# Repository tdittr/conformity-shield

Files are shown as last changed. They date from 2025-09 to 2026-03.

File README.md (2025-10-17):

# Conformity Shield

This is a design for a Arduino Uno R3 compatible shield, that connects an RP2354B to all IO pins. It is inteded to be used to test implementations of [`embedded-hal`](https://docs.rs/embedded-hal/).

**Warning:** rev1 of this board has known problems, do not produce boards from this yet, see the issue tracker for details!

## License

This project is licensed under the [CERN-OHL-P license](LICENSE), except for the contents of [`ProjectSpecific.pretty`](ProjectSpecific.pretty) and [`Project_Specific.kicad_sym`](Project_Specific.kicad_sym) which are partially copied from the [RP235xB example](https://datasheets.raspberrypi.com/rp2350/hardware-design-with-rp2350.pdf) by Raspberry Pi.

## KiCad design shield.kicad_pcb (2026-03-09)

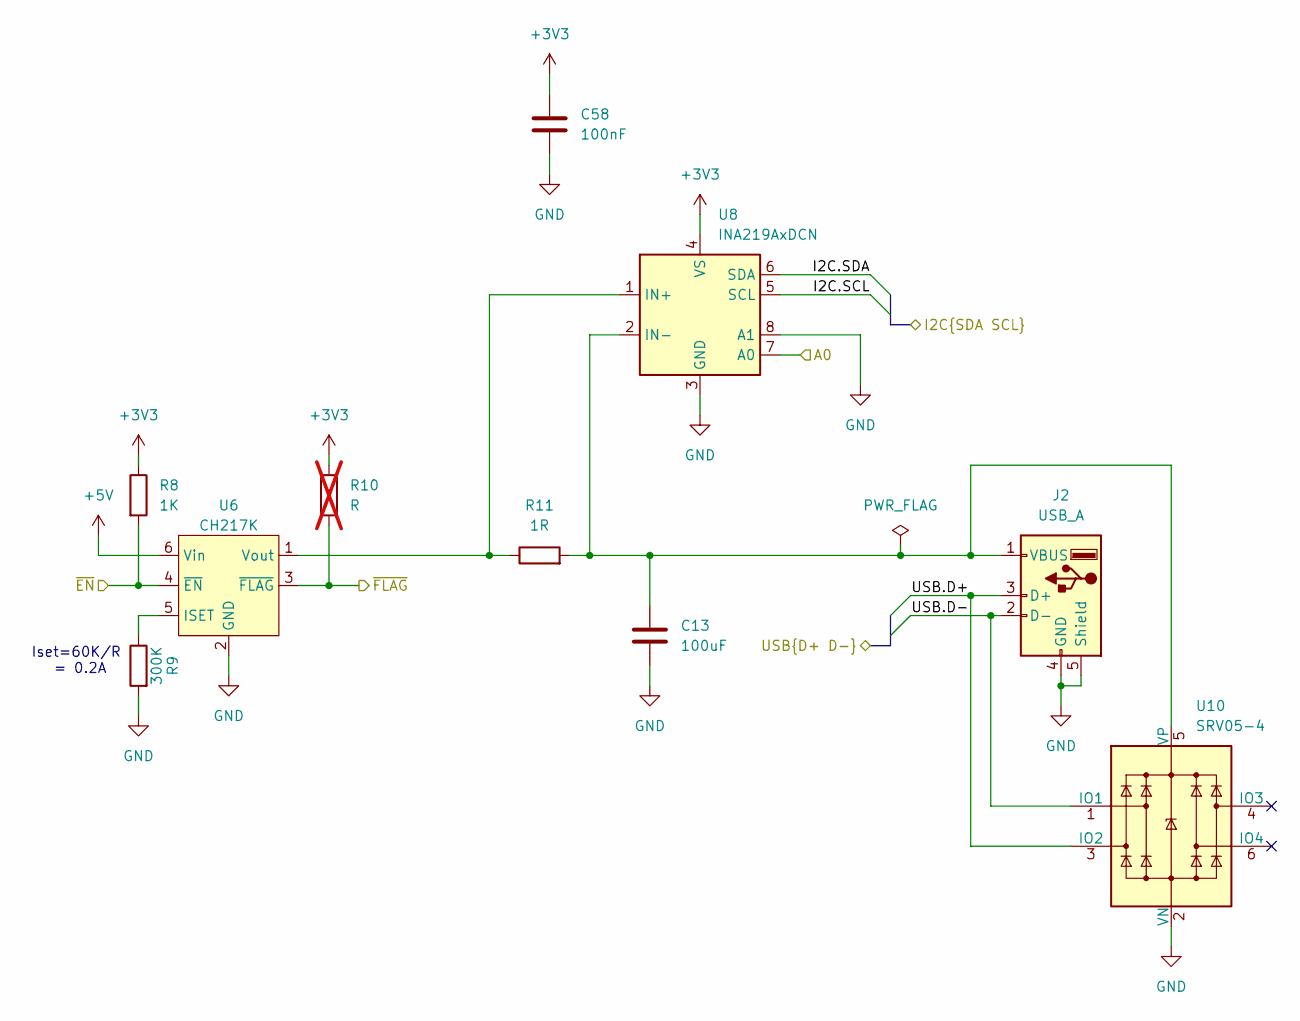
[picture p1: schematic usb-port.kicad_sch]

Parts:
C13: 100uF; C_1206_3216Metric; LCSC C15008
C58: 100nF; C_0402_1005Metric; LCSC C1525
J2: USB_A; USB_A_Receptacle_GCT_USB1046; LCSC C6307429
R8: 1K; R_0402_1005Metric; LCSC C11702
R9: 300K; R_0603_1608Metric; LCSC C23024
R10: R; R_0603_1608Metric_Pad0.98x0.95mm_HandSolder; not fitted
R11: 1R; R_0402_1005Metric; LCSC C25086
U6: CH217K; SOT-23-6; LCSC C7462749
U8: INA219AxDCN; SOT-23-8; LCSC C87469
U10: SRV05-4; SOT-23-6; LCSC C7420376

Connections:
+3V3: C58.1, R8.1, R10.1, U8.4 (VS), U8.7 (A0); also elsewhere on the board
+5V: U6.6 (Vin); also elsewhere on the board
/Tester/EN_USB_0: R8.2, U6.4 (~EN); also elsewhere on the board
/Tester/FLAG_USB_0: R10.2, U6.3 (~FLAG); also elsewhere on the board
/Tester/I2C.SCL: U8.5 (SCL); also elsewhere on the board
/Tester/I2C.SDA: U8.6 (SDA); also elsewhere on the board
/USB/USB1.D+: J2.3 (D+), U10.3 (IO2); also elsewhere on the board
/USB/USB1.D-: J2.2 (D-), U10.1 (IO1); also elsewhere on the board
GND: C13.2, C58.2, J2.4 (GND), J2.5 (Shield), R9.2, U6.2 (GND), U8.3 (GND), U8.8 (A1), U10.2 (VN); also elsewhere on the board
unnamed: C13.1, J2.1 (VBUS), R11.2, U8.2 (IN-), U10.5 (VP)
unnamed: R9.1, U6.5 (ISET)
unnamed: R11.1, U6.1 (Vout), U8.1 (IN+)

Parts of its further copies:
C52: 100uF; C_1206_3216Metric; LCSC C15008
C59: 100nF; C_0402_1005Metric; LCSC C1525
J3: USB_A; USB_A_Receptacle_GCT_USB1046; LCSC C6307429
R12: 1K; R_0402_1005Metric; LCSC C11702
R13: 300K; R_0603_1608Metric; LCSC C23024
R14: R; R_0603_1608Metric_Pad0.98x0.95mm_HandSolder; not fitted
R15: 1R; R_0402_1005Metric; LCSC C25086
U7: CH217K; SOT-23-6; LCSC C7462749
U9: INA219AxDCN; SOT-23-8; LCSC C87469
U11: SRV05-4; SOT-23-6; LCSC C7420376

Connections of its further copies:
+3V3: C59.1, R12.1, R14.1, U9.4 (VS); also elsewhere on the board
+5V: U7.6 (Vin); also elsewhere on the board
/Tester/EN_USB_1: R12.2, U7.4 (~EN); also elsewhere on the board
/Tester/FLAG_USB_1: R14.2, U7.3 (~FLAG); also elsewhere on the board
/Tester/I2C.SCL: U9.5 (SCL); also elsewhere on the board
/Tester/I2C.SDA: U9.6 (SDA); also elsewhere on the board
/USB Mux/USB.D+: J3.3 (D+), U11.3 (IO2); also elsewhere on the board
/USB Mux/USB.D-: J3.2 (D-), U11.1 (IO1); also elsewhere on the board
GND: C52.2, C59.2, J3.4 (GND), J3.5 (Shield), R13.2, U7.2 (GND), U9.3 (GND), U9.7 (A0), U9.8 (A1), U11.2 (VN); also elsewhere on the board
unnamed: C52.1, J3.1 (VBUS), R15.2, U9.2 (IN-), U11.5 (VP)
unnamed: R13.1, U7.5 (ISET)
unnamed: R15.1, U7.1 (Vout), U9.1 (IN+)

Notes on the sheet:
Iset=60K/R = 0.2A

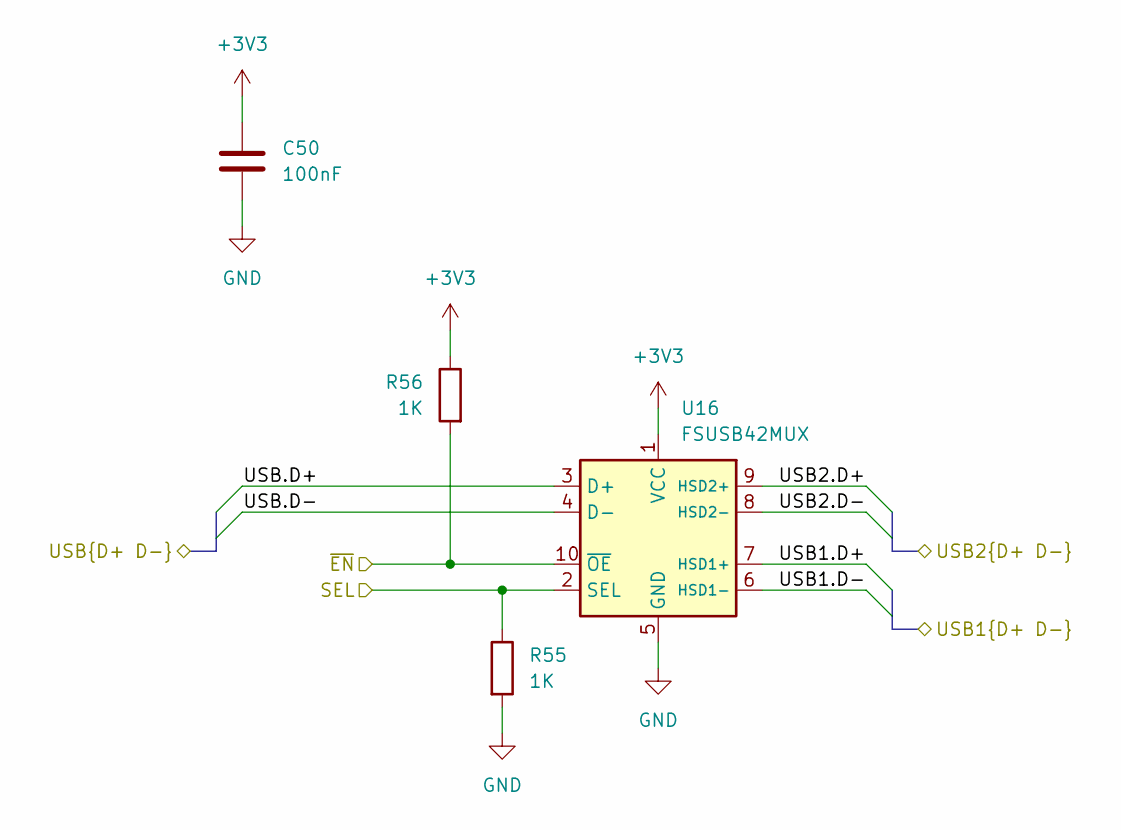
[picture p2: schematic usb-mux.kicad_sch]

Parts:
C50: 100nF; C_0402_1005Metric; LCSC C1525
R55, R56: 1K; R_0402_1005Metric; LCSC C11702
U16: FSUSB42MUX; MSOP-10_3x3mm_P0.5mm; LCSC C11355

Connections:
+3V3: C50.1, R56.1, U16.1 (VCC); also elsewhere on the board
/Tester/USBH.D+: U16.9 (HSD2+); also elsewhere on the board
/Tester/USBH.D-: U16.8 (HSD2-); also elsewhere on the board
/Tester/USBH_SEL: R55.1, U16.2 (SEL); also elsewhere on the board
/Tester/~USBH_EN: R56.2, U16.10 (~OE); also elsewhere on the board
/USB Mux/USB1.D+: U16.7 (HSD1+); also elsewhere on the board
/USB Mux/USB1.D-: U16.6 (HSD1-); also elsewhere on the board
/USB Mux/USB.D+: U16.3 (D+); also elsewhere on the board
/USB Mux/USB.D-: U16.4 (D-); also elsewhere on the board
GND: C50.2, R55.2, U16.5 (GND); also elsewhere on the board

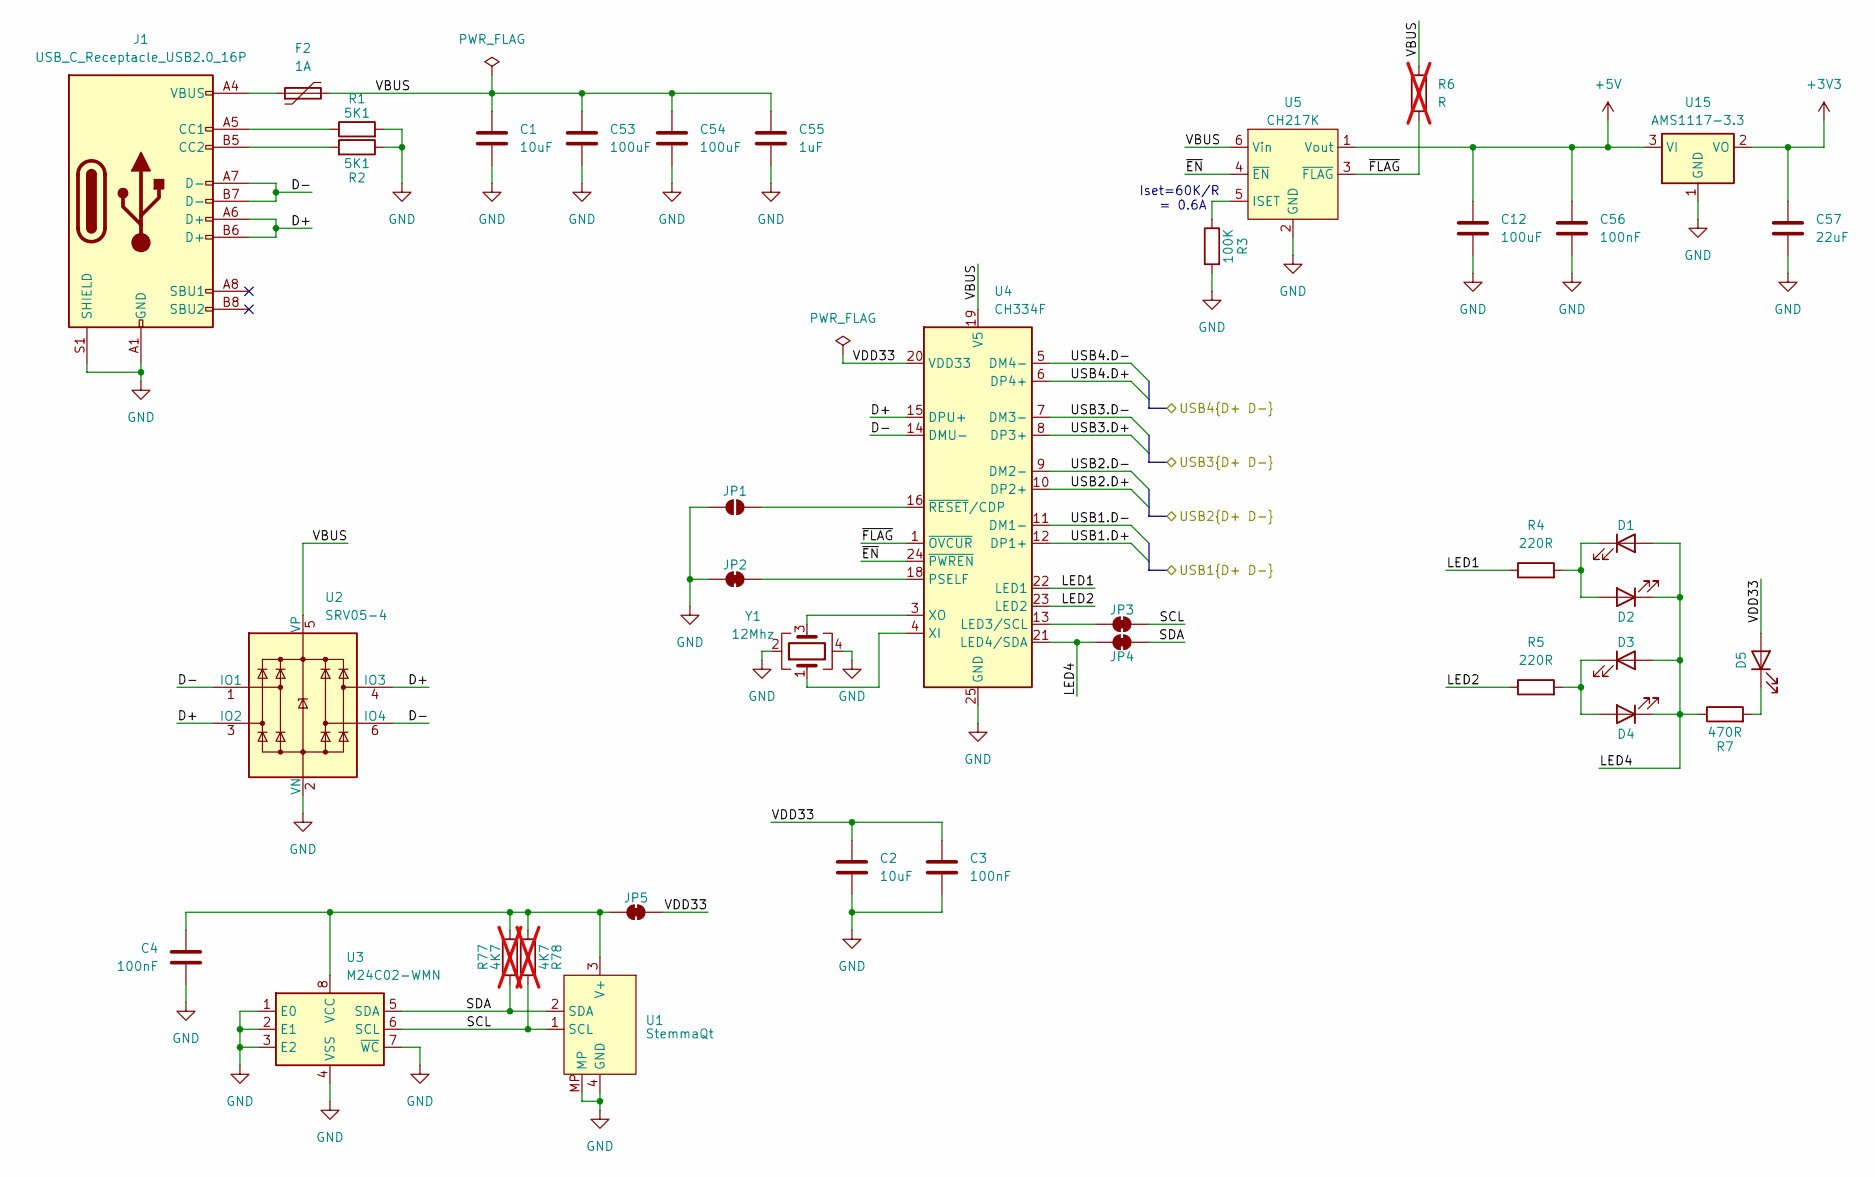
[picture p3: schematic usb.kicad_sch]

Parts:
C1, C2: 10uF; C_0402_1005Metric; LCSC C15525
C3, C4, C56: 100nF; C_0402_1005Metric; LCSC C1525
C12, C53, C54: 100uF; C_1206_3216Metric; LCSC C15008
C55: 1uF; C_0402_1005Metric; LCSC C52923
C57: 22uF; C_0805_2012Metric; LCSC C45783
D1, D2, D3, D4, D5: LED; LED_0805_2012Metric; LCSC C2297
F2: 1A; Fuse_1206_3216Metric_Pad1.42x1.75mm_HandSolder; LCSC C720075
J1: USB_C_Receptacle_USB2.0_16P; USB_C_Receptacle_G-Switch_GT-USB-7010ASV; LCSC C2988369
JP1: SolderJumper_2_Open; SolderJumper-2_P1.3mm_Open_RoundedPad1.0x1.5mm
JP2, JP3, JP4, JP5: SolderJumper_2_Bridged; SolderJumper-2_P1.3mm_Bridged_RoundedPad1.0x1.5mm
R1, R2: 5K1; R_0402_1005Metric; LCSC C25905
R3: 100K; R_0603_1608Metric; LCSC C23162
R4, R5: 220R; R_0402_1005Metric; LCSC C25091
R6: R; R_0603_1608Metric_Pad0.98x0.95mm_HandSolder; not fitted
R7: 470R; R_0402_1005Metric; LCSC C25117
R77, R78: 4K7; R_0402_1005Metric_Pad0.72x0.64mm_HandSolder; LCSC C25900; not fitted
U1: StemmaQt; JST_SH_SM04B-SRSS-TB_1x04-1MP_P1.00mm_Horizontal; LCSC C160404
U2: SRV05-4; SOT-23-6; LCSC C7420376
U3: M24C02-WMN; SOIC-8_3.9x4.9mm_P1.27mm; LCSC C7562
U4: CH334F; QFN-24-1EP_4x4mm_P0.5mm_EP2.7x2.7mm_ThermalVias; LCSC C5187527
U5: CH217K; SOT-23-6; LCSC C7462749
U15: AMS1117-3.3; SOT-223-3_TabPin2; LCSC C6186
Y1: 12Mhz; Crystal_SMD_3225-4Pin_3.2x2.5mm; LCSC C9002

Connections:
+3V3: C57.1, U15.2 (VO); also elsewhere on the board
+5V: C12.1, C56.1, U5.1 (Vout), U15.3 (VI); also elsewhere on the board
/Tester/USB.D+: U4.8 (DP3+); also elsewhere on the board
/Tester/USB.D-: U4.7 (DM3-); also elsewhere on the board
/USB Mux/USB1.D+: U4.10 (DP2+); also elsewhere on the board
/USB Mux/USB1.D-: U4.9 (DM2-); also elsewhere on the board
/USB/D+: J1.A6 (D+), J1.B6 (D+), U2.3 (IO2), U2.4 (IO3), U4.15 (DPU+)
/USB/D-: J1.A7 (D-), J1.B7 (D-), U2.1 (IO1), U2.6 (IO4), U4.14 (DMU-)
/USB/LED1: R4.1, U4.22 (LED1)
/USB/LED2: R5.1, U4.23 (LED2)
/USB/LED4: D1.2 (A), D2.1 (K), D3.2 (A), D4.1 (K), JP4.1 (A), R7.1, U4.21 (LED4/SDA)
/USB/SCL: JP3.2 (B), R78.1, U1.1 (SCL), U3.6 (SCL)
/USB/SDA: JP4.2 (B), R77.1, U1.2 (SDA), U3.5 (SDA)
/USB/USB1.D+: U4.12 (DP1+); also elsewhere on the board
/USB/USB1.D-: U4.11 (DM1-); also elsewhere on the board
/USB/USB4.D+: U4.6 (DP4+); also elsewhere on the board
/USB/USB4.D-: U4.5 (DM4-); also elsewhere on the board
/USB/VBUS: C1.1, C53.1, C54.1, C55.1, F2.2, R6.1, U2.5 (VP), U4.19 (V5), U5.6 (Vin)
/USB/VDD33: C2.1, C3.1, D5.2 (A), JP5.2 (B), U4.20 (VDD33)
/USB/~EN: U4.24 (~PWREN), U5.4 (~EN)
/USB/~FLAG: R6.2, U4.1 (~OVCUR), U5.3 (~FLAG)
GND: C1.2, C2.2, C3.2, C4.2, C12.2, C53.2, C54.2, C55.2, C56.2, C57.2, J1.A1 (GND), J1.A12 (GND), J1.B1 (GND), J1.B12 (GND), J1.S1 (SHIELD), JP1.1 (A), JP2.1 (A), R1.2, R2.1, R3.2, U1.4 (GND), U1.MP, U2.2 (VN), U3.1 (E0), U3.2 (E1), U3.3 (E2), U3.4 (VSS), U3.7 (~WC), U4.25 (GND), U5.2 (GND), U15.1 (GND), Y1.2, Y1.4; also elsewhere on the board
unnamed: D1.1 (K), D2.2 (A), R4.2
unnamed: D3.1 (K), D4.2 (A), R5.2
unnamed: D5.1 (K), R7.2
unnamed: F2.1, J1.A4 (VBUS), J1.A9 (VBUS), J1.B4 (VBUS), J1.B9 (VBUS)
unnamed: J1.A5 (CC1), R1.1
unnamed: J1.B5 (CC2), R2.2
unnamed: JP1.2 (B), U4.16 (~RESET/CDP)
unnamed: JP2.2 (B), U4.18 (PSELF)
unnamed: JP3.1 (A), U4.13 (LED3/SCL)
unnamed: C4.1, JP5.1 (A), R77.2, R78.2, U1.3 (V+), U3.8 (VCC)
unnamed: U4.4 (XI), Y1.1
unnamed: U4.3 (XO), Y1.3
unnamed: R3.1, U5.5 (ISET)

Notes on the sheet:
Iset=60K/R = 0.6A

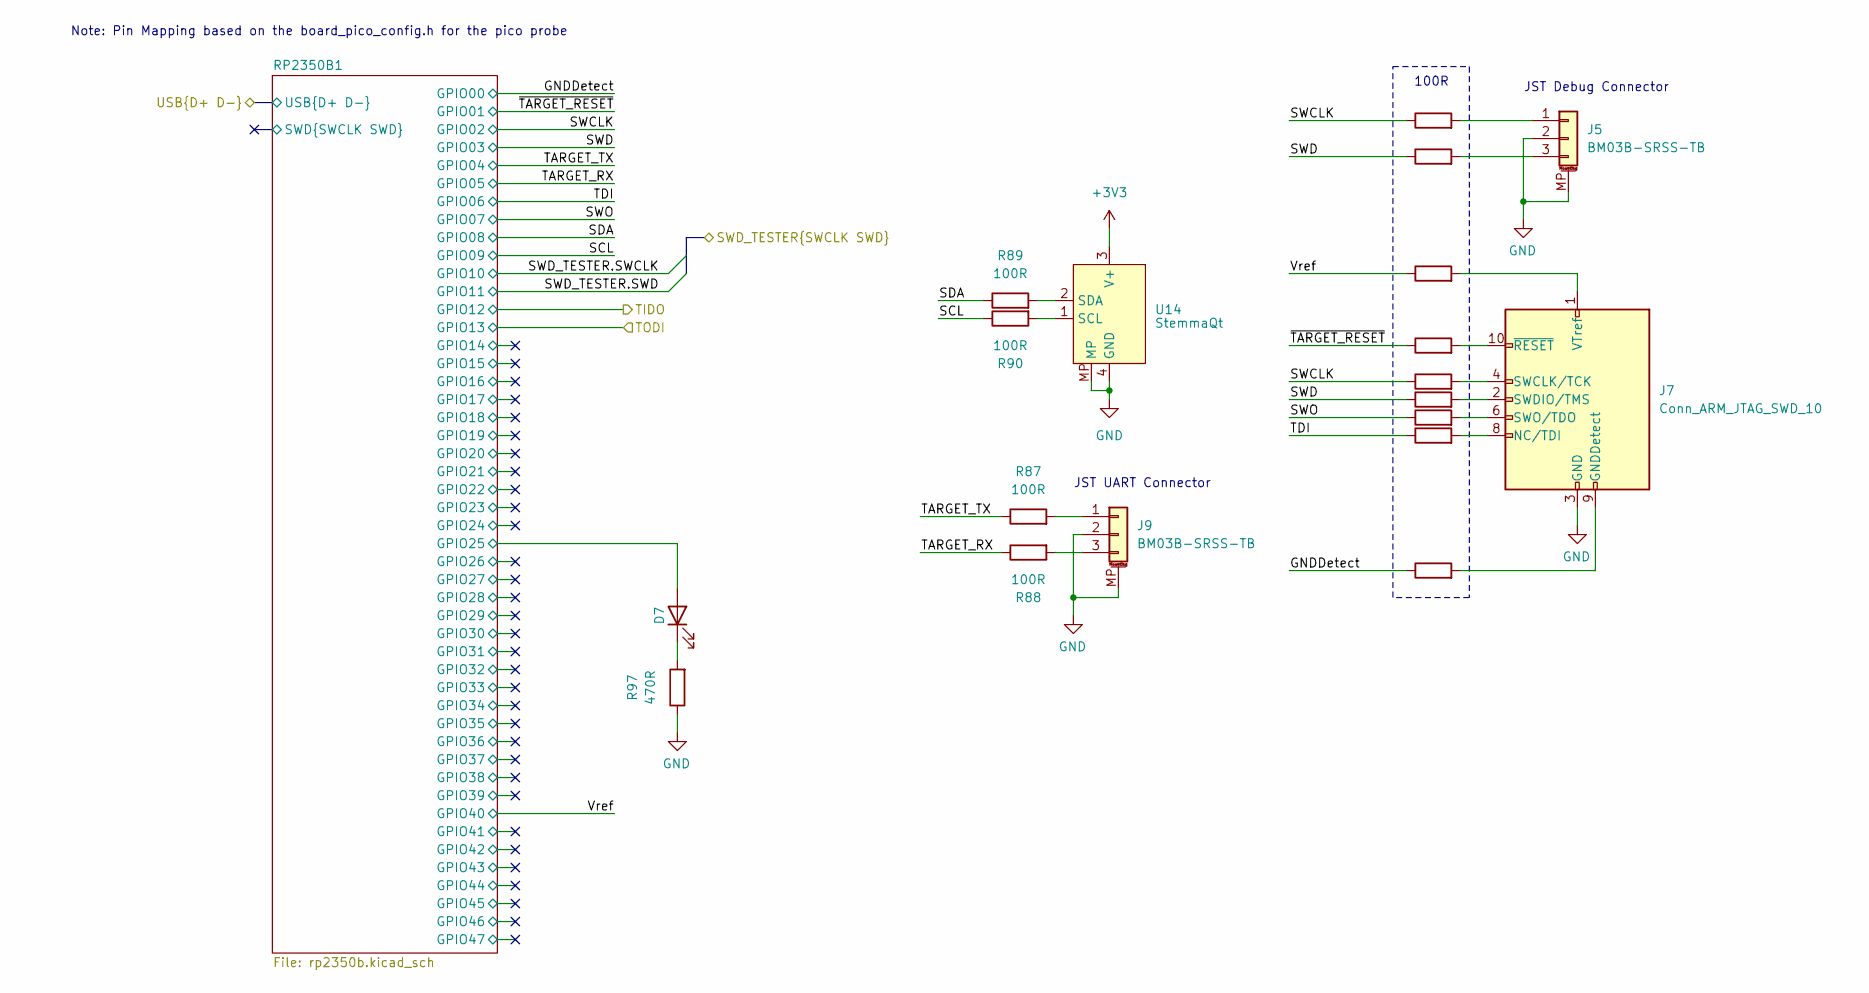
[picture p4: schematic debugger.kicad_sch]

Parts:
D7: LED; LED_0805_2012Metric; LCSC C2297
J5, J9: BM03B-SRSS-TB; JST_SH_BM03B-SRSS-TB_1x03-1MP_P1.00mm_Vertical; LCSC C160389
J7: Conn_ARM_JTAG_SWD_10; PinHeader_2x05_P1.27mm_Vertical_SMD_IDC; LCSC C42372555
R69, R70, R71, R72, R73, R74, R81, R85, R86, R87, R88, R89, R90: 100R; R_0402_1005Metric_Pad0.72x0.64mm_HandSolder; LCSC C25076
R97: 470R; R_0402_1005Metric_Pad0.72x0.64mm_HandSolder; LCSC C25117
U14: StemmaQt; JST_SH_SM04B-SRSS-TB_1x04-1MP_P1.00mm_Horizontal; LCSC C160404

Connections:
+3V3: U14.3 (V+); also elsewhere on the board
/debugger/GNDDetect: R81.1; also elsewhere on the board
/debugger/RP2350B1/GPIO25: D7.2 (A); also elsewhere on the board
/debugger/SCL: R90.1; also elsewhere on the board
/debugger/SDA: R89.1; also elsewhere on the board
/debugger/SWCLK: R71.1, R85.1; also elsewhere on the board
/debugger/SWD: R72.1, R86.1; also elsewhere on the board
/debugger/SWO: R73.1; also elsewhere on the board
/debugger/TARGET_RX: R88.1; also elsewhere on the board
/debugger/TARGET_TX: R87.1; also elsewhere on the board
/debugger/TDI: R74.1; also elsewhere on the board
/debugger/Vref: R69.1; also elsewhere on the board
/debugger/~TARGET_RESET: R70.1; also elsewhere on the board
GND: J5.2, J5.MP (MountPin), J7.3 (GND), J7.5 (GND), J9.2, J9.MP (MountPin), R97.1, U14.4 (GND), U14.MP; also elsewhere on the board
unnamed: D7.1 (K), R97.2
unnamed: J5.1, R85.2
unnamed: J5.3, R86.2
unnamed: J7.9 (GNDDetect), R81.2
unnamed: J7.8 (NC/TDI), R74.2
unnamed: J7.4 (SWCLK/TCK), R71.2
unnamed: J7.2 (SWDIO/TMS), R72.2
unnamed: J7.6 (SWO/TDO), R73.2
unnamed: J7.1 (VTref), R69.2
unnamed: J7.10 (~RESET), R70.2
unnamed: J9.1, R87.2
unnamed: J9.3, R88.2
unnamed: R90.2, U14.1 (SCL)
unnamed: R89.2, U14.2 (SDA)

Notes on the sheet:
Note: Pin Mapping based on the board_pico_config.h for the pico probe
JST UART Connector
100R
JST Debug Connector

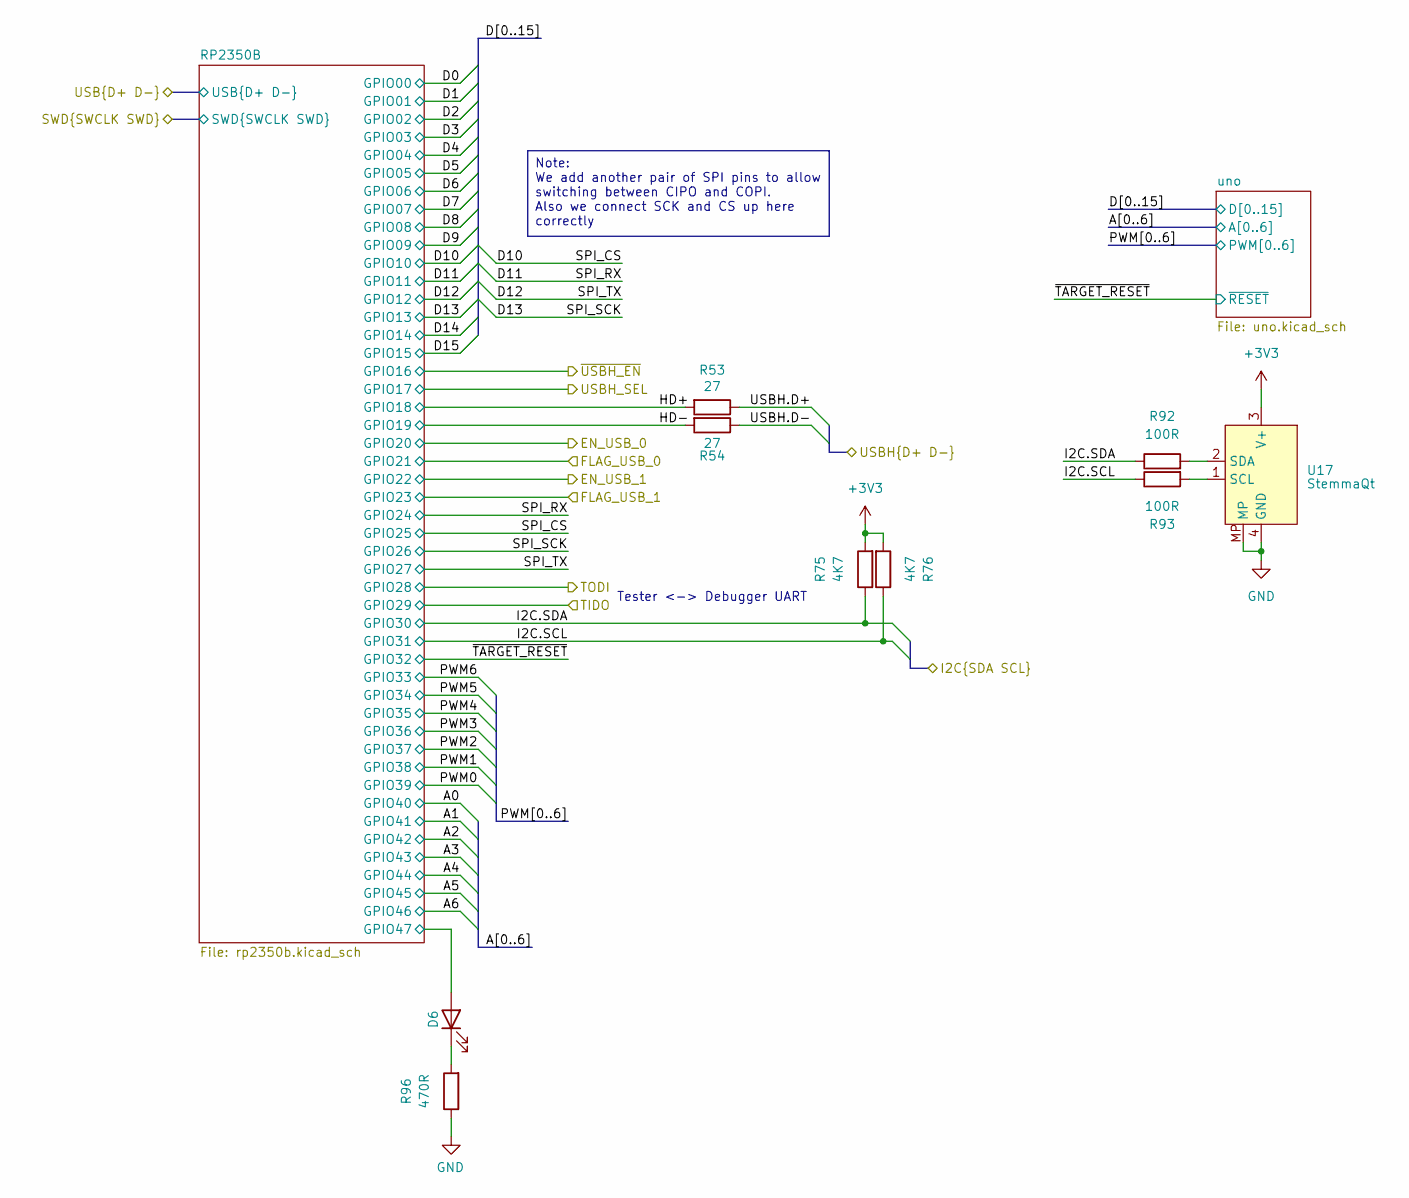
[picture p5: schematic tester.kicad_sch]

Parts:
D6: LED; LED_0805_2012Metric; LCSC C2297
R53, R54: 27; R_0402_1005Metric; LCSC C138021
R75, R76: 4K7; R_0402_1005Metric_Pad0.72x0.64mm_HandSolder; LCSC C25900
R92, R93: 100R; R_0402_1005Metric_Pad0.72x0.64mm_HandSolder; LCSC C25076
R96: 470R; R_0402_1005Metric_Pad0.72x0.64mm_HandSolder; LCSC C25117
U17: StemmaQt; JST_SH_SM04B-SRSS-TB_1x04-1MP_P1.00mm_Horizontal; LCSC C160404

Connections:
+3V3: R75.2, R76.2, U17.3 (V+); also elsewhere on the board
/Tester/HD+: R53.2; also elsewhere on the board
/Tester/HD-: R54.2; also elsewhere on the board
/Tester/I2C.SCL: R76.1, R93.1; also elsewhere on the board
/Tester/I2C.SDA: R75.1, R92.1; also elsewhere on the board
/Tester/RP2350B/GPIO47: D6.2 (A); also elsewhere on the board
/Tester/USBH.D+: R53.1; also elsewhere on the board
/Tester/USBH.D-: R54.1; also elsewhere on the board
GND: R96.1, U17.4 (GND), U17.MP; also elsewhere on the board
unnamed: D6.1 (K), R96.2
unnamed: R93.2, U17.1 (SCL)
unnamed: R92.2, U17.2 (SDA)

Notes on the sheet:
Tester <-> Debugger UART
Note: We add another pair of SPI pins to allow switching between CIPO and COPI. Also we connect SCK and CS up here correctly

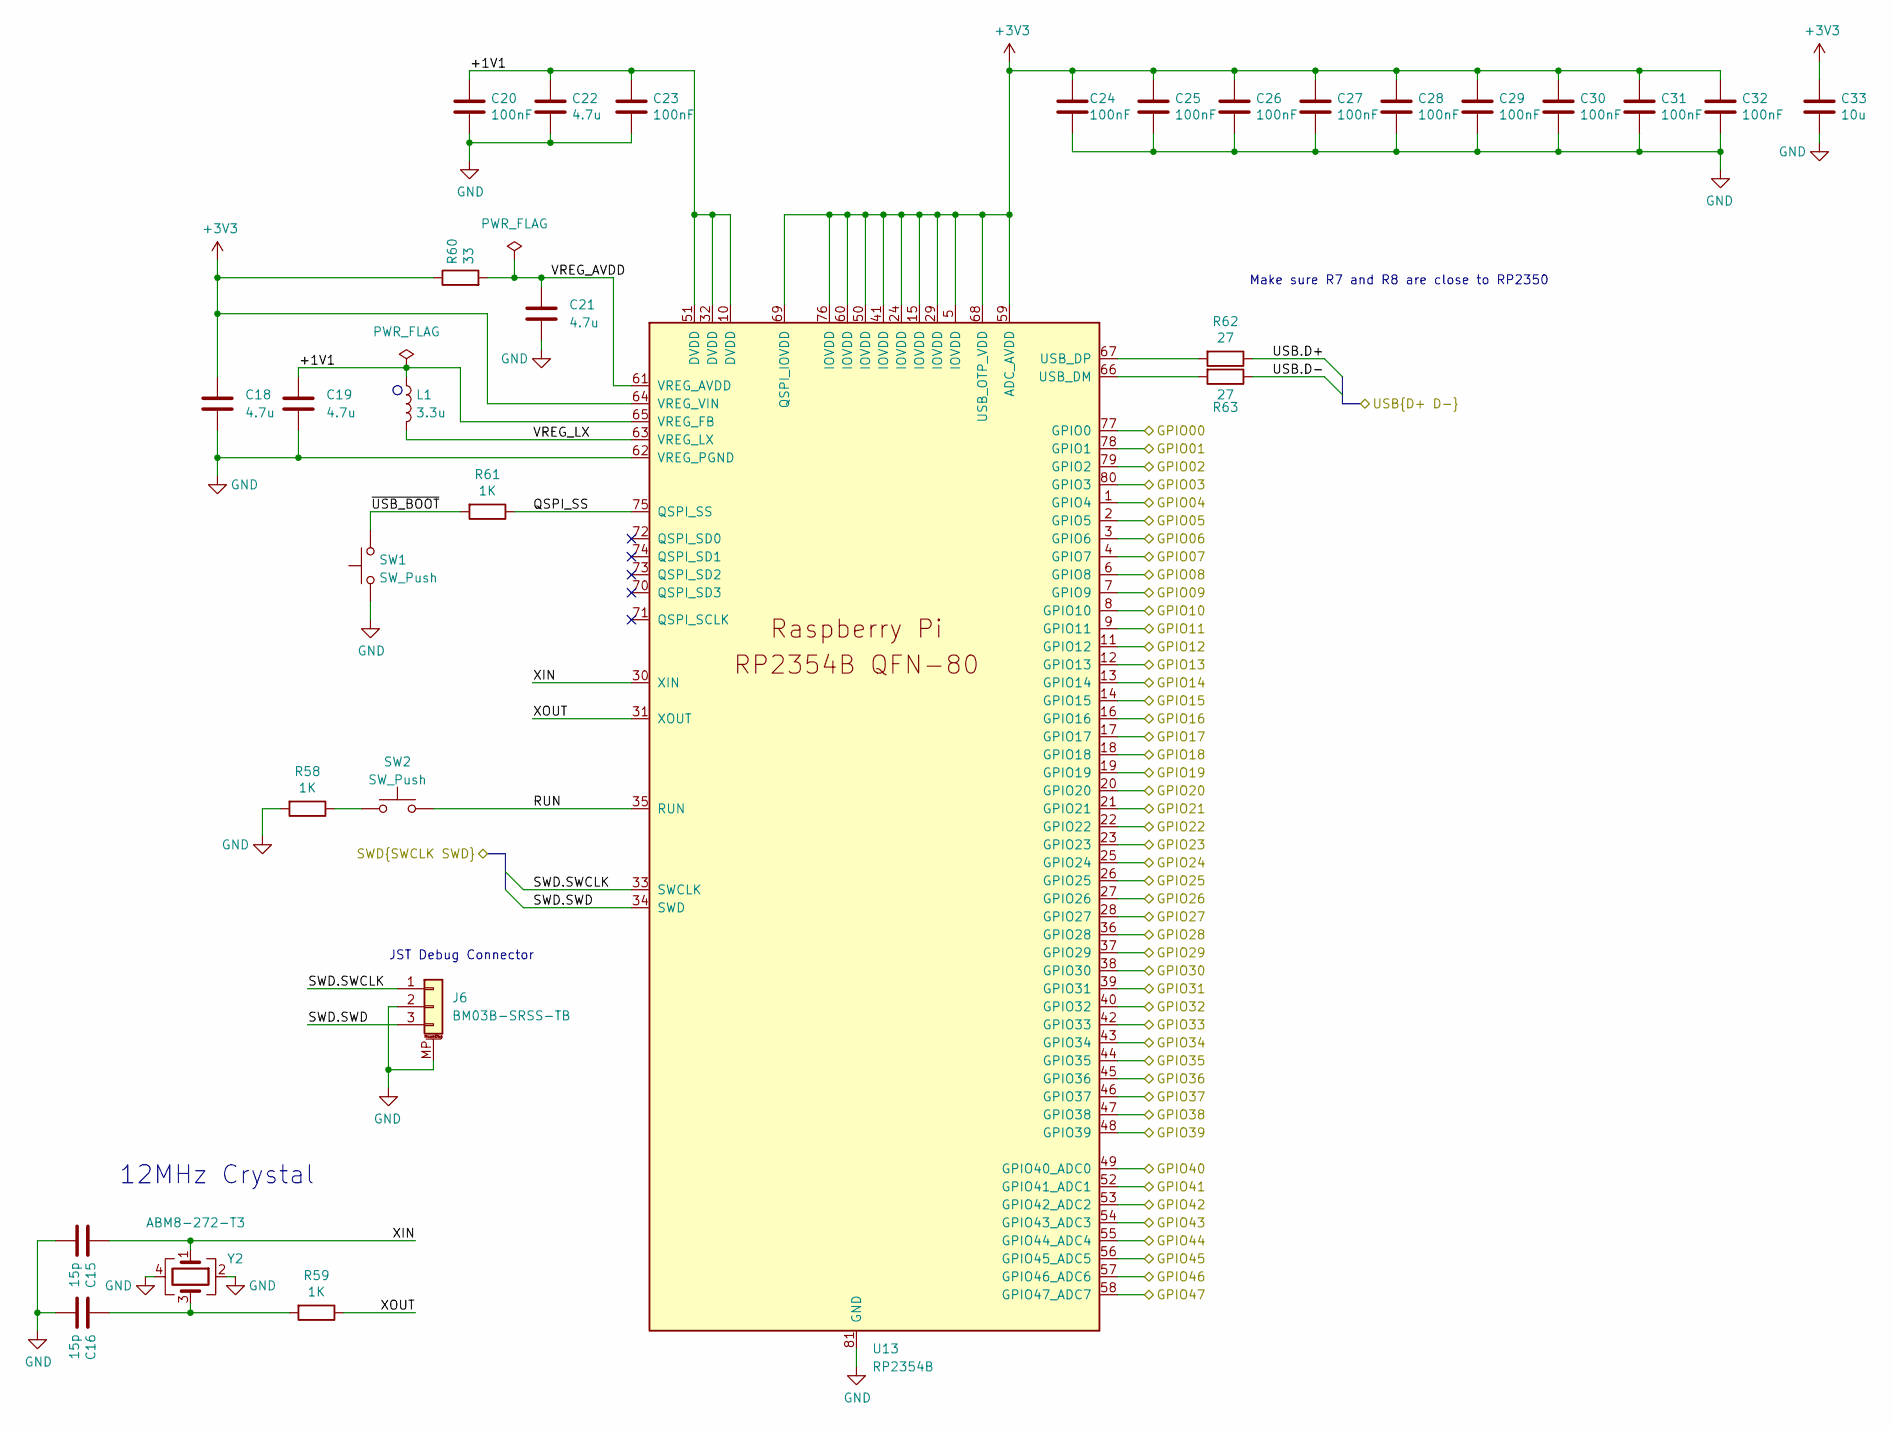
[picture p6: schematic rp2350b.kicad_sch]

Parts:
C15, C16: 15p; C_0402_1005Metric; LCSC C1548
C18, C19: 4.7u; C_0402_1005Metric_small_pads; LCSC C23733
C20, C23, C24, C25, C26, C27, C28, C29, C30, C31, C32: 100nF; C_0402_1005Metric; LCSC C1525
C21, C22: 4.7u; C_0402_1005Metric; LCSC C23733
C33: 10u; C_0805_2012Metric; LCSC C15850
J6: BM03B-SRSS-TB; JST_SH_BM03B-SRSS-TB_1x03-1MP_P1.00mm_Vertical; LCSC C160389
L1: 3.3u; L_pol_2016; LCSC C42411119
R58, R59, R61: 1K; R_0402_1005Metric; LCSC C11702
R60: 33; R_0402_1005Metric; LCSC C25105
R62, R63: 27; R_0402_1005Metric; LCSC C138021
SW1, SW2: SW_Push; SW_Push_1P1T_XKB_TS-1187A; LCSC C318884
U13: RP2354B; QFN-80-1EP_10x10mm_P0.4mm_EP3.4x3.4mm_ThermalVias; LCSC C39843328
Y2: ABM8-272-T3; Crystal_SMD_3225-4Pin_3.2x2.5mm; LCSC C20625731

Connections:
+3V3: C18.1, C24.1, C25.1, C26.1, C27.1, C28.1, C29.1, C30.1, C31.1, C32.1, C33.1, R60.1, U13.5 (IOVDD), U13.15 (IOVDD), U13.24 (IOVDD), U13.29 (IOVDD), U13.41 (IOVDD), U13.50 (IOVDD), U13.59 (ADC_AVDD), U13.60 (IOVDD), U13.64 (VREG_VIN), U13.68 (USB_OTP_VDD), U13.69 (QSPI_IOVDD), U13.76 (IOVDD); also elsewhere on the board
/Tester/A0: U13.49 (GPIO40_ADC0); also elsewhere on the board
/Tester/A1: U13.52 (GPIO41_ADC1); also elsewhere on the board
/Tester/A2: U13.53 (GPIO42_ADC2); also elsewhere on the board
/Tester/A3: U13.54 (GPIO43_ADC3); also elsewhere on the board
/Tester/A4: U13.55 (GPIO44_ADC4); also elsewhere on the board
/Tester/A5: U13.56 (GPIO45_ADC5); also elsewhere on the board
/Tester/A6: U13.57 (GPIO46_ADC6); also elsewhere on the board
/Tester/D0: U13.77 (GPIO0); also elsewhere on the board
/Tester/D1: U13.78 (GPIO1); also elsewhere on the board
/Tester/D2: U13.79 (GPIO2); also elsewhere on the board
/Tester/D3: U13.80 (GPIO3); also elsewhere on the board
/Tester/D4: U13.1 (GPIO4); also elsewhere on the board
/Tester/D5: U13.2 (GPIO5); also elsewhere on the board
/Tester/D6: U13.3 (GPIO6); also elsewhere on the board
/Tester/D7: U13.4 (GPIO7); also elsewhere on the board
/Tester/D8: U13.6 (GPIO8); also elsewhere on the board
/Tester/D9: U13.7 (GPIO9); also elsewhere on the board
/Tester/D10: U13.8 (GPIO10), U13.26 (GPIO25); also elsewhere on the board
/Tester/D11: U13.9 (GPIO11), U13.25 (GPIO24); also elsewhere on the board
/Tester/D12: U13.11 (GPIO12), U13.28 (GPIO27); also elsewhere on the board
/Tester/D13: U13.12 (GPIO13), U13.27 (GPIO26); also elsewhere on the board
/Tester/D14: U13.13 (GPIO14); also elsewhere on the board
/Tester/D15: U13.14 (GPIO15); also elsewhere on the board
/Tester/EN_USB_0: U13.20 (GPIO20); also elsewhere on the board
/Tester/EN_USB_1: U13.22 (GPIO22); also elsewhere on the board
/Tester/FLAG_USB_0: U13.21 (GPIO21); also elsewhere on the board
/Tester/FLAG_USB_1: U13.23 (GPIO23); also elsewhere on the board
/Tester/HD+: U13.18 (GPIO18); also elsewhere on the board
/Tester/HD-: U13.19 (GPIO19); also elsewhere on the board
/Tester/I2C.SCL: U13.39 (GPIO31); also elsewhere on the board
/Tester/I2C.SDA: U13.38 (GPIO30); also elsewhere on the board
/Tester/PWM0: U13.48 (GPIO39); also elsewhere on the board
/Tester/PWM1: U13.47 (GPIO38); also elsewhere on the board
/Tester/PWM2: U13.46 (GPIO37); also elsewhere on the board
/Tester/PWM3: U13.45 (GPIO36); also elsewhere on the board
/Tester/PWM4: U13.44 (GPIO35); also elsewhere on the board
/Tester/PWM5: U13.43 (GPIO34); also elsewhere on the board
/Tester/PWM6: U13.42 (GPIO33); also elsewhere on the board
/Tester/RP2350B/+1V1: C19.1, C20.1, C22.1, C23.1, L1.1, U13.10 (DVDD), U13.32 (DVDD), U13.51 (DVDD), U13.65 (VREG_FB)
/Tester/RP2350B/GPIO47: U13.58 (GPIO47_ADC7); also elsewhere on the board
/Tester/RP2350B/QSPI_SS: R61.1, U13.75 (QSPI_SS)
/Tester/RP2350B/RUN: SW2.2, U13.35 (RUN)
/Tester/RP2350B/VREG_AVDD: C21.1, R60.2, U13.61 (VREG_AVDD)
/Tester/RP2350B/VREG_LX: L1.2, U13.63 (VREG_LX)
/Tester/RP2350B/XIN: C15.1, U13.30 (XIN), Y2.1
/Tester/RP2350B/XOUT: R59.1, U13.31 (XOUT)
/Tester/RP2350B/~USB_BOOT: R61.2, SW1.2
/Tester/SWD.SWCLK: J6.1, U13.33 (SWCLK); also elsewhere on the board
/Tester/SWD.SWD: J6.3, U13.34 (SWD); also elsewhere on the board
/Tester/TIDO: U13.37 (GPIO29); also elsewhere on the board
/Tester/TODI: U13.36 (GPIO28); also elsewhere on the board
/Tester/USB.D+: R62.1; also elsewhere on the board
/Tester/USB.D-: R63.1; also elsewhere on the board
/Tester/USBH_SEL: U13.17 (GPIO17); also elsewhere on the board
/Tester/~TARGET_RESET: U13.40 (GPIO32); also elsewhere on the board
/Tester/~USBH_EN: U13.16 (GPIO16); also elsewhere on the board
GND: C15.2, C16.2, C18.2, C19.2, C20.2, C21.2, C22.2, C23.2, C24.2, C25.2, C26.2, C27.2, C28.2, C29.2, C30.2, C31.2, C32.2, C33.2, J6.2, J6.MP (MountPin), R58.2, SW1.1, U13.62 (VREG_PGND), U13.81 (GND), Y2.2, Y2.4; also elsewhere on the board
unnamed: C16.1, R59.2, Y2.3
unnamed: R58.1, SW2.1
unnamed: R63.2, U13.66 (USB_DM)
unnamed: R62.2, U13.67 (USB_DP)

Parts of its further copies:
C14, C17: 15p; C_0402_1005Metric; LCSC C1548
C34, C35: 4.7u; C_0402_1005Metric_small_pads; LCSC C23733
C36, C39, C40, C41, C42, C43, C44, C45, C46, C47, C48: 100nF; C_0402_1005Metric; LCSC C1525
C37, C38: 4.7u; C_0402_1005Metric; LCSC C23733
C49: 10u; C_0805_2012Metric; LCSC C15850
J4: BM03B-SRSS-TB; JST_SH_BM03B-SRSS-TB_1x03-1MP_P1.00mm_Vertical; LCSC C160389
L2: 3.3u; L_pol_2016; LCSC C42411119
R57, R64, R66: 1K; R_0402_1005Metric; LCSC C11702
R65: 33; R_0402_1005Metric; LCSC C25105
R67, R68: 27; R_0402_1005Metric; LCSC C138021
SW3, SW4: SW_Push; SW_Push_1P1T_XKB_TS-1187A; LCSC C318884
U12: RP2354B; QFN-80-1EP_10x10mm_P0.4mm_EP3.4x3.4mm_ThermalVias; LCSC C39843328
Y3: ABM8-272-T3; Crystal_SMD_3225-4Pin_3.2x2.5mm; LCSC C20625731

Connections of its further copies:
+3V3: C34.1, C40.1, C41.1, C42.1, C43.1, C44.1, C45.1, C46.1, C47.1, C48.1, C49.1, R65.1, U12.5 (IOVDD), U12.15 (IOVDD), U12.24 (IOVDD), U12.29 (IOVDD), U12.41 (IOVDD), U12.50 (IOVDD), U12.59 (ADC_AVDD), U12.60 (IOVDD), U12.64 (VREG_VIN), U12.68 (USB_OTP_VDD), U12.69 (QSPI_IOVDD), U12.76 (IOVDD); also elsewhere on the board
/Tester/SWD.SWCLK: U12.8 (GPIO10); also elsewhere on the board
/Tester/SWD.SWD: U12.9 (GPIO11); also elsewhere on the board
/Tester/TIDO: U12.11 (GPIO12); also elsewhere on the board
/Tester/TODI: U12.12 (GPIO13); also elsewhere on the board
/USB/USB4.D+: R67.1; also elsewhere on the board
/USB/USB4.D-: R68.1; also elsewhere on the board
/debugger/GNDDetect: U12.77 (GPIO0); also elsewhere on the board
/debugger/RP2350B1/+1V1: C35.1, C36.1, C38.1, C39.1, L2.1, U12.10 (DVDD), U12.32 (DVDD), U12.51 (DVDD), U12.65 (VREG_FB)
/debugger/RP2350B1/GPIO14: U12.13 (GPIO14)
/debugger/RP2350B1/GPIO15: U12.14 (GPIO15)
/debugger/RP2350B1/GPIO16: U12.16 (GPIO16)
/debugger/RP2350B1/GPIO17: U12.17 (GPIO17)
/debugger/RP2350B1/GPIO18: U12.18 (GPIO18)
/debugger/RP2350B1/GPIO19: U12.19 (GPIO19)
/debugger/RP2350B1/GPIO20: U12.20 (GPIO20)
/debugger/RP2350B1/GPIO21: U12.21 (GPIO21)
/debugger/RP2350B1/GPIO22: U12.22 (GPIO22)
/debugger/RP2350B1/GPIO23: U12.23 (GPIO23)
/debugger/RP2350B1/GPIO24: U12.25 (GPIO24)
/debugger/RP2350B1/GPIO25: U12.26 (GPIO25); also elsewhere on the board
/debugger/RP2350B1/GPIO26: U12.27 (GPIO26)
/debugger/RP2350B1/GPIO27: U12.28 (GPIO27)
/debugger/RP2350B1/GPIO28: U12.36 (GPIO28)
/debugger/RP2350B1/GPIO29: U12.37 (GPIO29)
/debugger/RP2350B1/GPIO30: U12.38 (GPIO30)
/debugger/RP2350B1/GPIO31: U12.39 (GPIO31)
/debugger/RP2350B1/GPIO32: U12.40 (GPIO32)
/debugger/RP2350B1/GPIO33: U12.42 (GPIO33)
/debugger/RP2350B1/GPIO34: U12.43 (GPIO34)
/debugger/RP2350B1/GPIO35: U12.44 (GPIO35)
/debugger/RP2350B1/GPIO36: U12.45 (GPIO36)
/debugger/RP2350B1/GPIO37: U12.46 (GPIO37)
/debugger/RP2350B1/GPIO38: U12.47 (GPIO38)
/debugger/RP2350B1/GPIO39: U12.48 (GPIO39)
/debugger/RP2350B1/GPIO41: U12.52 (GPIO41_ADC1)
/debugger/RP2350B1/GPIO42: U12.53 (GPIO42_ADC2)
/debugger/RP2350B1/GPIO43: U12.54 (GPIO43_ADC3)
/debugger/RP2350B1/GPIO44: U12.55 (GPIO44_ADC4)
/debugger/RP2350B1/GPIO45: U12.56 (GPIO45_ADC5)
/debugger/RP2350B1/GPIO46: U12.57 (GPIO46_ADC6)
/debugger/RP2350B1/GPIO47: U12.58 (GPIO47_ADC7)
/debugger/RP2350B1/QSPI_SS: R66.1, U12.75 (QSPI_SS)
/debugger/RP2350B1/RUN: SW4.2, U12.35 (RUN)
/debugger/RP2350B1/SWD.SWCLK: J4.1, U12.33 (SWCLK)
/debugger/RP2350B1/SWD.SWD: J4.3, U12.34 (SWD)
/debugger/RP2350B1/VREG_AVDD: C37.1, R65.2, U12.61 (VREG_AVDD)
/debugger/RP2350B1/VREG_LX: L2.2, U12.63 (VREG_LX)
/debugger/RP2350B1/XIN: C14.1, U12.30 (XIN), Y3.1
/debugger/RP2350B1/XOUT: R64.1, U12.31 (XOUT)
/debugger/RP2350B1/~USB_BOOT: R66.2, SW3.2
/debugger/SCL: U12.7 (GPIO9); also elsewhere on the board
/debugger/SDA: U12.6 (GPIO8); also elsewhere on the board
/debugger/SWCLK: U12.79 (GPIO2); also elsewhere on the board
/debugger/SWD: U12.80 (GPIO3); also elsewhere on the board
/debugger/SWO: U12.4 (GPIO7); also elsewhere on the board
/debugger/TARGET_RX: U12.2 (GPIO5); also elsewhere on the board
/debugger/TARGET_TX: U12.1 (GPIO4); also elsewhere on the board
/debugger/TDI: U12.3 (GPIO6); also elsewhere on the board
/debugger/Vref: U12.49 (GPIO40_ADC0); also elsewhere on the board
/debugger/~TARGET_RESET: U12.78 (GPIO1); also elsewhere on the board
GND: C14.2, C17.2, C34.2, C35.2, C36.2, C37.2, C38.2, C39.2, C40.2, C41.2, C42.2, C43.2, C44.2, C45.2, C46.2, C47.2, C48.2, C49.2, J4.2, J4.MP (MountPin), R57.2, SW3.1, U12.62 (VREG_PGND), U12.81 (GND), Y3.2, Y3.4; also elsewhere on the board
unnamed: C17.1, R64.2, Y3.3
unnamed: R57.1, SW4.1
unnamed: R68.2, U12.66 (USB_DM)
unnamed: R67.2, U12.67 (USB_DP)

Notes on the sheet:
12MHz Crystal
Make sure R7 and R8 are close to RP2350
JST Debug Connector

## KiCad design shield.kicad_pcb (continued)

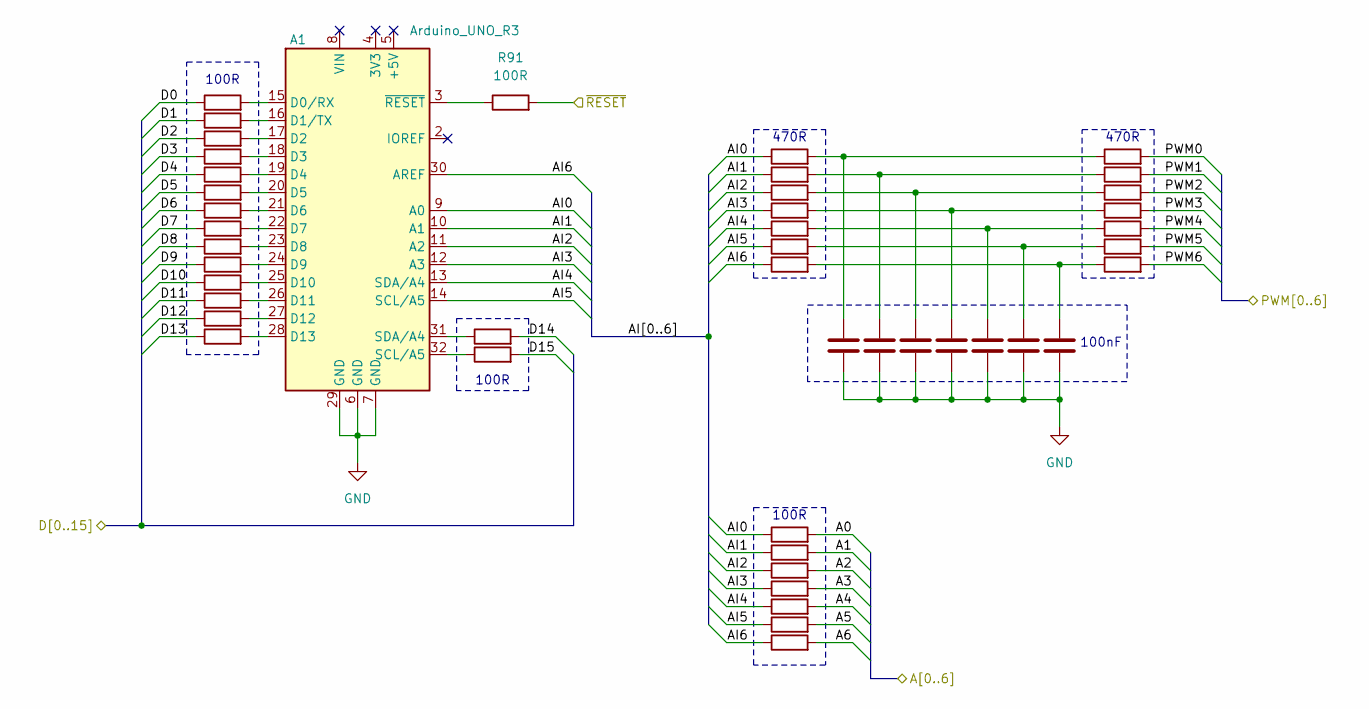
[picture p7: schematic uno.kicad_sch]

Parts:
A1: Arduino_UNO_R3; Arduino_UNO_R3_ShieldBase
C5, C6, C7, C8, C9, C10, C11: 100nF; C_0402_1005Metric_Pad0.74x0.62mm_HandSolder; LCSC C1525
R16, R17, R18, R19, R20, R21, R22, R23, R24, R25, R26, R27, R28, R29, R30, R31, R39, R40, R41, R42, R43, R44, R45, R91: 100R; R_0402_1005Metric_Pad0.72x0.64mm_HandSolder; LCSC C25076
R32, R33, R34, R35, R36, R37, R38, R46, R47, R48, R49, R50, R51, R52: 470R; R_0402_1005Metric_Pad0.72x0.64mm_HandSolder; LCSC C25117

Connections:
/Tester/A0: R39.2; also elsewhere on the board
/Tester/A1: R40.2; also elsewhere on the board
/Tester/A2: R41.2; also elsewhere on the board
/Tester/A3: R42.2; also elsewhere on the board
/Tester/A4: R43.2; also elsewhere on the board
/Tester/A5: R44.2; also elsewhere on the board
/Tester/A6: R45.2; also elsewhere on the board
/Tester/D0: R16.1; also elsewhere on the board
/Tester/D1: R17.1; also elsewhere on the board
/Tester/D2: R18.1; also elsewhere on the board
/Tester/D3: R19.1; also elsewhere on the board
/Tester/D4: R20.1; also elsewhere on the board
/Tester/D5: R21.1; also elsewhere on the board
/Tester/D6: R22.1; also elsewhere on the board
/Tester/D7: R23.1; also elsewhere on the board
/Tester/D8: R24.1; also elsewhere on the board
/Tester/D9: R25.1; also elsewhere on the board
/Tester/D10: R26.1; also elsewhere on the board
/Tester/D11: R27.1; also elsewhere on the board
/Tester/D12: R28.1; also elsewhere on the board
/Tester/D13: R29.1; also elsewhere on the board
/Tester/D14: R30.2; also elsewhere on the board
/Tester/D15: R31.2; also elsewhere on the board
/Tester/PWM0: R46.2; also elsewhere on the board
/Tester/PWM1: R47.2; also elsewhere on the board
/Tester/PWM2: R48.2; also elsewhere on the board
/Tester/PWM3: R49.2; also elsewhere on the board
/Tester/PWM4: R50.2; also elsewhere on the board
/Tester/PWM5: R51.2; also elsewhere on the board
/Tester/PWM6: R52.2; also elsewhere on the board
/Tester/uno/AI0: A1.9 (A0), R32.1, R39.1
/Tester/uno/AI1: A1.10 (A1), R33.1, R40.1
/Tester/uno/AI2: A1.11 (A2), R34.1, R41.1
/Tester/uno/AI3: A1.12 (A3), R35.1, R42.1
/Tester/uno/AI4: A1.13 (SDA/A4), R36.1, R43.1
/Tester/uno/AI5: A1.14 (SCL/A5), R37.1, R44.1
/Tester/uno/AI6: A1.30 (AREF), R38.1, R45.1
/Tester/~TARGET_RESET: R91.2; also elsewhere on the board
GND: A1.6 (GND), A1.7 (GND), A1.29 (GND), C5.2, C6.2, C7.2, C8.2, C9.2, C10.2, C11.2; also elsewhere on the board
unnamed: A1.15 (D0/RX), R16.2
unnamed: A1.16 (D1/TX), R17.2
unnamed: A1.17 (D2), R18.2
unnamed: A1.18 (D3), R19.2
unnamed: A1.19 (D4), R20.2
unnamed: A1.20 (D5), R21.2
unnamed: A1.21 (D6), R22.2
unnamed: A1.22 (D7), R23.2
unnamed: A1.23 (D8), R24.2
unnamed: A1.24 (D9), R25.2
unnamed: A1.25 (D10), R26.2
unnamed: A1.26 (D11), R27.2
unnamed: A1.27 (D12), R28.2
unnamed: A1.28 (D13), R29.2
unnamed: A1.32 (SCL/A5), R31.1
unnamed: A1.31 (SDA/A4), R30.1
unnamed: A1.3 (~RESET), R91.1
unnamed: C5.1, R32.2, R46.1
unnamed: C6.1, R33.2, R47.1
unnamed: C7.1, R34.2, R48.1
unnamed: C8.1, R35.2, R49.1
unnamed: C9.1, R36.2, R50.1
unnamed: C10.1, R37.2, R51.1
unnamed: C11.1, R38.2, R52.1

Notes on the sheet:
470R
100R
100nF

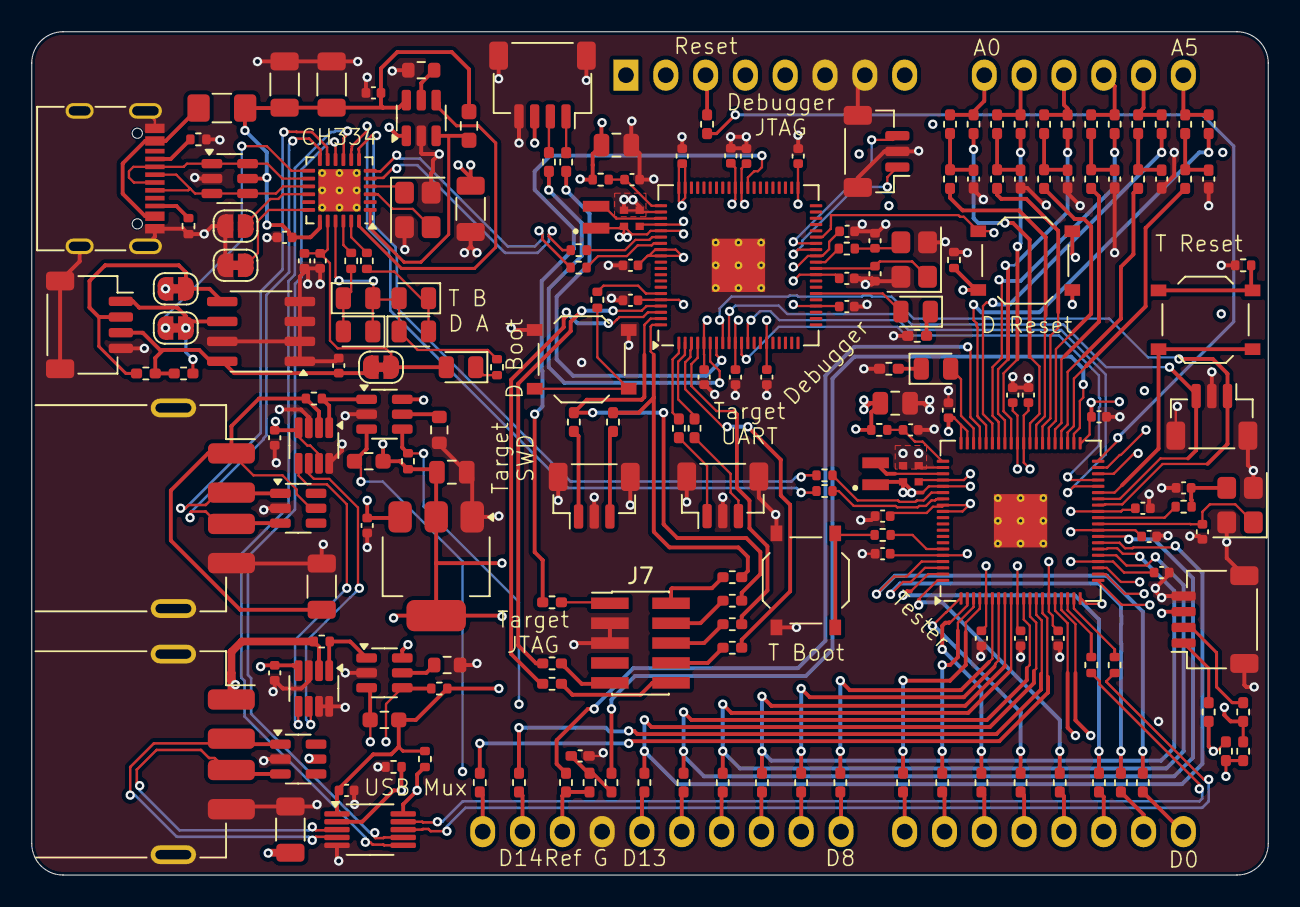
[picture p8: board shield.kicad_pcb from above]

Board: 4 copper layers, 78.9 x 53.8 mm, 196 parts (0 on the bottom side), 177 nets.

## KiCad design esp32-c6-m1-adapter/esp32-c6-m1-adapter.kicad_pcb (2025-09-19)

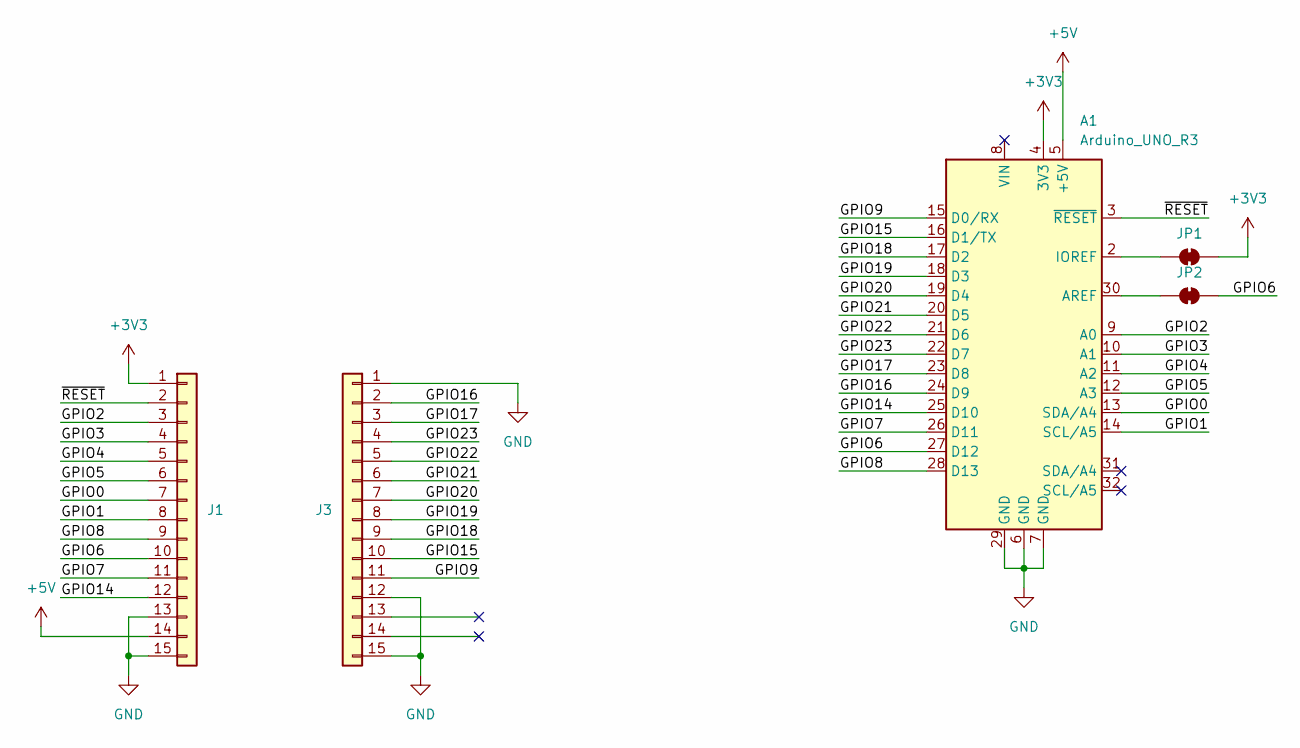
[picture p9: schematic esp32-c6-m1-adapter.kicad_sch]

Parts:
A1: Arduino_UNO_R3; Arduino_UNO_R3_ShieldBase
J1, J3: Conn_01x15; PinHeader_1x15_P2.54mm_Vertical
JP1, JP2: SolderJumper_2_Bridged; SolderJumper-2_P1.3mm_Bridged_RoundedPad1.0x1.5mm

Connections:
+3V3: A1.4 (3V3), J1.1, JP1.2 (B)
+5V: A1.5 (+5V), J1.14
/GPIO0: A1.13 (SDA/A4), J1.7
/GPIO1: A1.14 (SCL/A5), J1.8
/GPIO2: A1.9 (A0), J1.3
/GPIO3: A1.10 (A1), J1.4
/GPIO4: A1.11 (A2), J1.5
/GPIO5: A1.12 (A3), J1.6
/GPIO6: A1.27 (D12), J1.10, JP2.2 (B)
/GPIO7: A1.26 (D11), J1.11
/GPIO8: A1.28 (D13), J1.9
/GPIO9: A1.15 (D0/RX), J3.11
/GPIO14: A1.25 (D10), J1.12
/GPIO15: A1.16 (D1/TX), J3.10
/GPIO16: A1.24 (D9), J3.2
/GPIO17: A1.23 (D8), J3.3
/GPIO18: A1.17 (D2), J3.9
/GPIO19: A1.18 (D3), J3.8
/GPIO20: A1.19 (D4), J3.7
/GPIO21: A1.20 (D5), J3.6
/GPIO22: A1.21 (D6), J3.5
/GPIO23: A1.22 (D7), J3.4
/~RESET: A1.3 (~RESET), J1.2
GND: A1.6 (GND), A1.7 (GND), A1.29 (GND), J1.13, J1.15, J3.1, J3.12, J3.15
unnamed: A1.30 (AREF), JP2.1 (A)
unnamed: A1.2 (IOREF), JP1.1 (A)

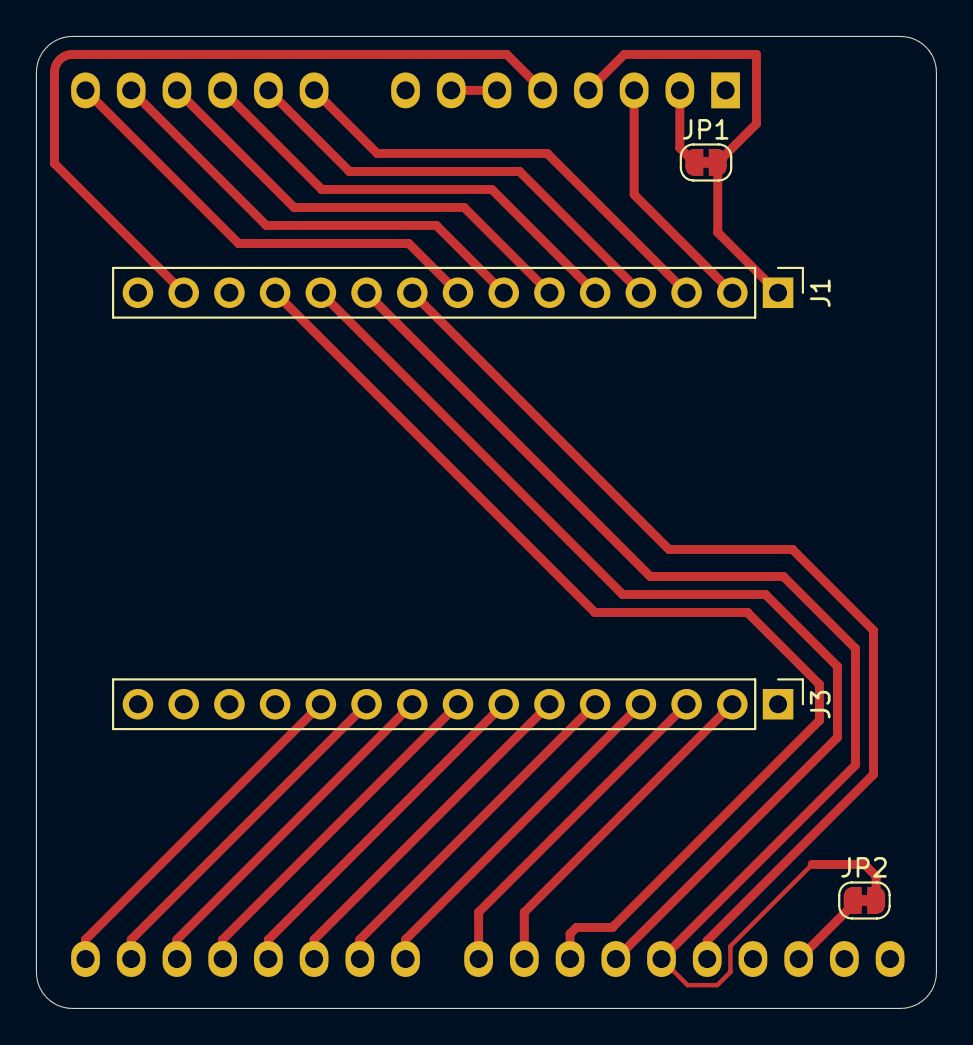
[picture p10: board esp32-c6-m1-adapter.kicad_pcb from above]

Board: 2 copper layers, 50.0 x 54.0 mm, 5 parts (1 on the bottom side), 26 nets.

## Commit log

2025-07-25 Initial draft for USB hub
    [shield.kicad_pcb, shield.kicad_sch, usb.kicad_sch]
2025-07-25 Add Uno shield
    [shield.kicad_pcb, shield.kicad_sch, uno.kicad_sch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]
2025-08-18 Add RP2350B from example
    [rp2350b.kicad_sch, shield.kicad_sch, uno.kicad_sch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]
2025-08-22 Break out RP2350
    [debugger.kicad_sch, rp2350b.kicad_sch, shield.kicad_sch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]
2025-08-25 Do pin assignment for tester
    [debugger.kicad_sch, rp2350b.kicad_sch, shield.kicad_sch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]
2025-08-27 Start Layout
    [debugger.kicad_sch, rp2350b.kicad_sch, shield.kicad_pcb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]
2025-08-29 Layout Tester and USB Hub
    [debugger.kicad_sch, shield.kicad_pcb, tester.kicad_sch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]
2025-09-18 finished routing
    [shield.kicad_pcb]
2025-09-19 layout finished
    [rp2350b.kicad_sch, shield.kicad_pcb]
2025-09-19 JLC rotations
    [debugger.kicad_sch, rp2350b.kicad_sch, shield.kicad_pcb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]
2025-09-19 Fix JTAG IDC
    [debugger.kicad_sch, shield.kicad_pcb]
2025-09-19 Add ESP32-C6 adapter
    [esp32-c6-m1-adapter.kicad_pcb, esp32-c6-m1-adapter.kicad_sch]
2026-01-23 Fix rev1 errors
    Add USB mux to allow for USB PIO
    Fix D+ D- mixup
    Fix USB Hub LED indicator label
    [shield.kicad_pcb, shield.kicad_sch, tester.kicad_sch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]
2026-03-09 Address board review comments
    - Add pull-ups for both I2C busses (4K7)
    - Set eFuse limit to 600mA (400mA before)
    - Label StemmaQt as such in schematics
    - Fix typo in USB Port value
    - Fix USB Mux to be disabled by default (pull-down to pull-up)
    [debugger.kicad_sch, shield.kicad_pcb, tester.kicad_sch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]
